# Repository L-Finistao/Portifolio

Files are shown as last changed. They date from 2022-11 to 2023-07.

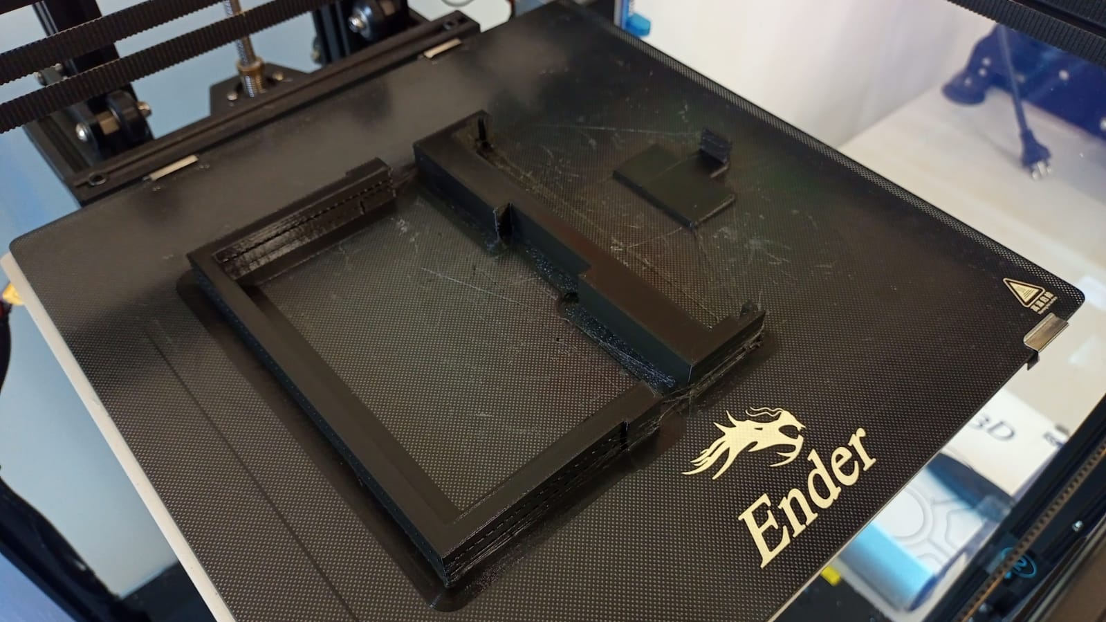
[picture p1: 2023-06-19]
Projeto/Fotos da montagem/Processo de impressão/impressão 08.jpg

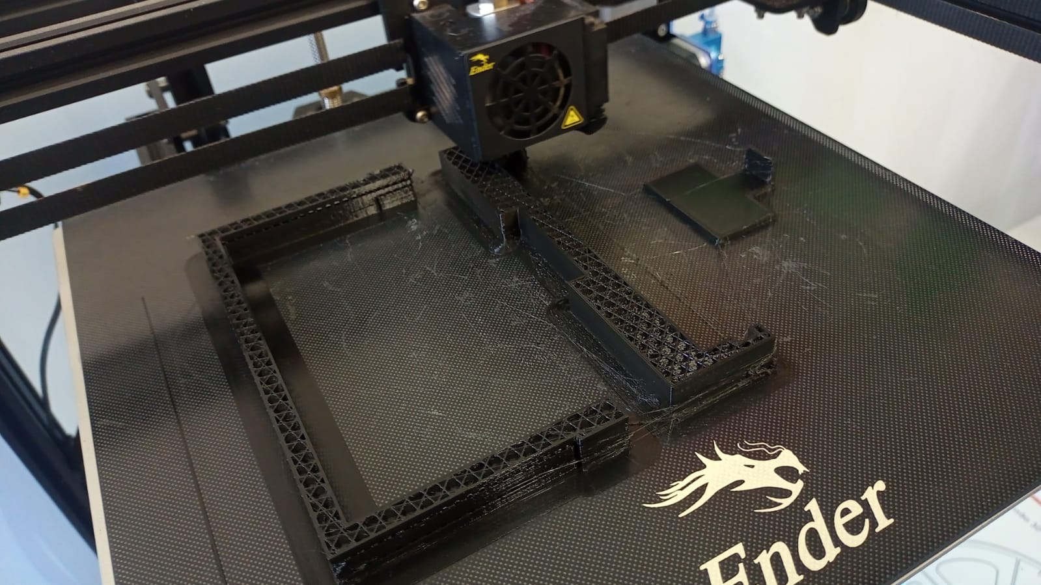
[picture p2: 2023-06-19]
Projeto/Fotos da montagem/Processo de impressão/impressão 01.jpg

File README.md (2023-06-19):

# Portifolio
Repositório de Portfólio para a matéria de Projeto Integrador I (PPRE8) IFSP Birigui-SP

Com o Link abaixo e possivel acessar o artigo que estamos Produzindo no Overleaf.

https://www.overleaf.com/read/fhdvfpwshqqs

## Projeto Robokeeper: Desenvolvimento de um Goleiro Robô

No projeto que desenvolvi, abordei a metodologia e os materiais utilizados para criar um goleiro robô chamado **Robokeeper** ou **Finisgol**. Meu objetivo era desenvolver um goleiro automatizado capaz de defender bolas em um jogo de futebol.

Na minha pesquisa, descrevi as etapas do projeto, começando pela análise e teste dos resultados, seguida pela otimização e melhorias. Organizei a metodologia em etapas para facilitar a compreensão e execução de cada atividade, o que contribuiu para o cumprimento dos meus objetivos e a validação dos resultados.

Além disso, apresentei um cronograma das atividades, detalhando as ações que seriam executadas até a Avaliação Final do Projeto. As etapas incluíram:

1. Levantamento dos componentes necessários.
2. Análise da viabilidade de utilizar visão computacional ou sensores ultrassônicos.
3. Prototipação do projeto por software.
4. Validação dos componentes.
5. Realização do orçamento.
6. Prototipação física.
7. Teste do protótipo.
8. Discussão e avaliação do projeto desenvolvido.
9. Entrega final do projeto.

Durante minha revisão bibliográfica, pesquisei informações sobre os motores de passo, destacando os diferentes tipos disponíveis no mercado e suas características. Optei pelo motor de passo "28byj-48", um motor de passo chinês com bom custo-benefício e especificações adequadas às necessidades do meu projeto.

Também abordei o sensor ultrassônico HC-SR04, explicando suas partes principais e seu funcionamento em três etapas. Esse sensor emite ondas ultrassônicas, recebe o eco do sinal emitido e calcula o tempo entre a emissão e a recepção do sinal para determinar a distância até um obstáculo.

Outro componente mencionado foi o LED (Light Emitting Diode), que é um dispositivo semicondutor capaz de transformar energia elétrica em luz. Expliquei os princípios de funcionamento dos LEDs e sua polarização.

No contexto do meu projeto, decidi entre utilizar visão computacional ou sensores ultrassônicos para captar o movimento da bola. Considerando meu conhecimento prévio, o tempo disponível, o custo e a complexidade da visão computacional, optei por utilizar sensores ultrassônicos para captar o movimento da bola.

Durante o desenvolvimento do projeto, adotei as seguintes etapas:

1. Estudo sobre o "Robokeeper" original.
2. Implementação de protótipos utilizando visão computacional e simuladores de circuitos Arduino.
3. Análise dos componentes mecânicos.
4. Montagem do protótipo físico.
5. Refinamento do software e componentes mecânicos.
6. Realização de testes para verificar o funcionamento do projeto.

Resumindo, descrevi a metodologia e os materiais utilizados no meu projeto de desenvolvimento de um goleiro robô, abordando desde a análise dos resultados até os testes finais. Apresentei informações sobre os

 motores de passo, sensores ultrassônicos, LEDs e minha escolha entre visão computacional e sensores ultrassônicos. Meu objetivo foi contribuir para a propagação da tecnologia robótica e o avanço das possibilidades na área de automação e inteligência artificial.

[Mapa Mental](/MapaMental.pdf)

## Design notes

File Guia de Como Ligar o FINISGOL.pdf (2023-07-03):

Manual Para Ligar e Operar FinisGOL
Problemas Não Resolvidos:

Botões:
Depois de soldado os fios foram analisados que o tipo de botão usado necessita de um resistor na extremidade do Fio.

Como Ligar?
Recomendo pedir ajuda ao Junior ou outro técnico para regular a Fonte de Tensão.

Pelos Botões Não estarem Funcionando Modifiquei o Código do Programa para Ligar sem a Necessidade do Botão. Código Disponível em Portfólio\Projeto\Código Alternativo Sem Botão no Github.
*Codigo já No Esp32

Verifique se os Fios Terras e Positivo estão ligados entre si e conectado a fonte geradora de Tensão.

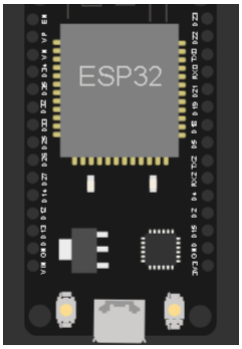
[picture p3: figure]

O Esp Utilizado tem essas Pinagens, o Terra que estamos unindo com o Motor é o mostrado abaixo

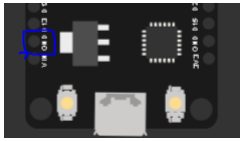
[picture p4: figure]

A Ligação do Motor Com a Ponte H é a seguinte.

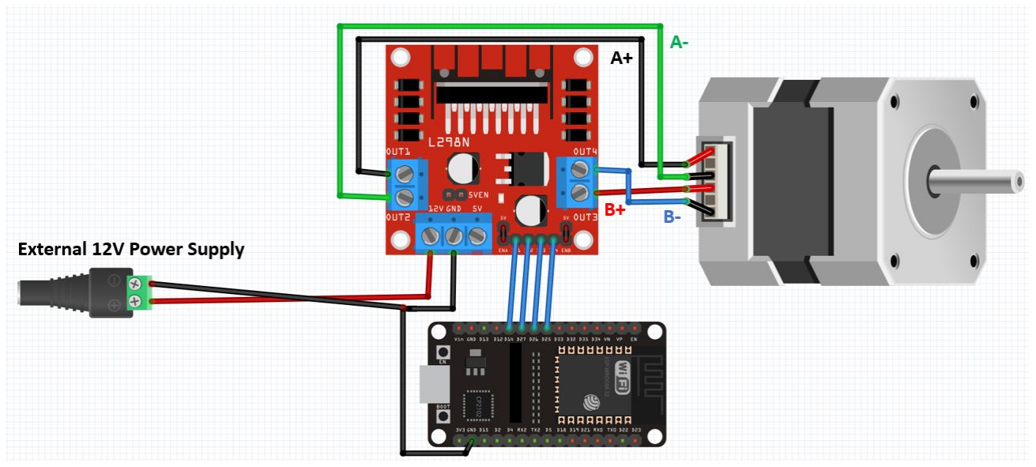
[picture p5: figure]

O Elemento na Imagem External 12V Power Supply utilizo a Fonte de Tensão que deixei proximo ao Projeto NO IF MAKER Certifique Se o Jumper que sai da Ponte H esteja ligado no Fio Vermelho do Gerador de Tensão e Corrente. e a junção entre o Terra da placa é ponte h no preto do Gerador.

Para que o Motor Opera na Faixa Ideal deve se regular A Fonte para Tensão: 12v e Corrente: 1.5A menos que isso o Motor/Goleiro apenas Vibra não Roda.

No Teste em Casa utilizei as Baterias mas pelo consumo do motor não foi viável manter pois após diminuir a tensão delas o motor não Roda, pois mesmo associando baterias para gerar a Tensão e Corrente Ideal em Pouco tempo ele fica em escala inferior ao Ideal.

O Esp 32 está conectado a um adaptador 12v que tem um botão para ligar a energia do Esp 32 o mesmo está conectado a Um Carregador. se não o ligar o esp 32 não Funcionará.

Identificação Visual de Funcionamento:

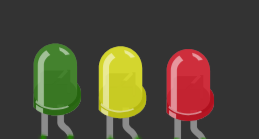
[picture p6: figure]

Ao Ligar o Esp 32 e Energizar Corretamente. o Led Verde Deve acender. ao Detectar um Objeto ele Aciona o Led Amarelo por 5 segundo ele deve voltar para o Verde

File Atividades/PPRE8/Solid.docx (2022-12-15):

O que é solid?

Solid (derivado de "dados vinculados a redes sociais") é um conjunto proposto de convenções e ferramentas para a construção de aplicativos sociais descentralizados com base nos princípios de dados vinculados. O Solid é modular e extensível e depende tanto quanto possível dos padrões e protocolos

Alguém já ouviu falar?

Só do termo SOLID que é um acrônimo para cinco postulados de design, destinados a facilitar a compreensão, o desenvolvimento e a manutenção de software.

Quem propôs?

Prof. Tim Berners-Lee, inventor da World Wide Web

Finalidade?

Verdadeira propriedade dos dados

Os usuários devem ter a liberdade de escolher onde seus dados residem e quem tem permissão para acessá-los. Ao desacoplar o conteúdo do próprio aplicativo, os usuários agora podem fazer isso.

Design modular

Como os aplicativos são desacoplados dos dados que produzem, os usuários poderão evitar o bloqueio do fornecedor, alternando perfeitamente entre aplicativos e servidores de armazenamento de dados pessoais, sem perder dados ou conexões sociais.

Reutilizando dados existentes

Os desenvolvedores poderão inovar facilmente criando novos aplicativos ou aprimorando os aplicativos atuais, enquanto reutilizam os dados existentes que foram criados por outros aplicativos.

Existe material em Português?

Não Encontramos

Como está a divulgação desse projeto? Como ficamos sabendo?

Não está sendo eficaz, através da professora.

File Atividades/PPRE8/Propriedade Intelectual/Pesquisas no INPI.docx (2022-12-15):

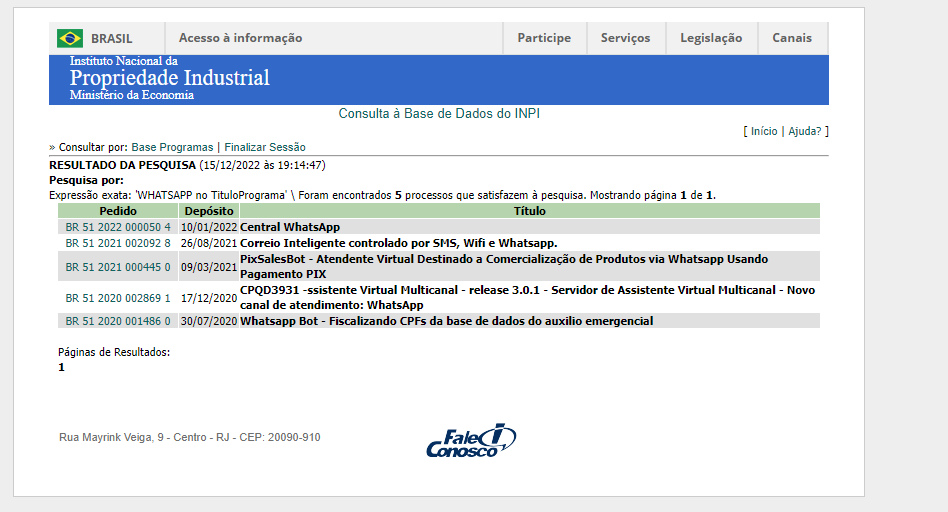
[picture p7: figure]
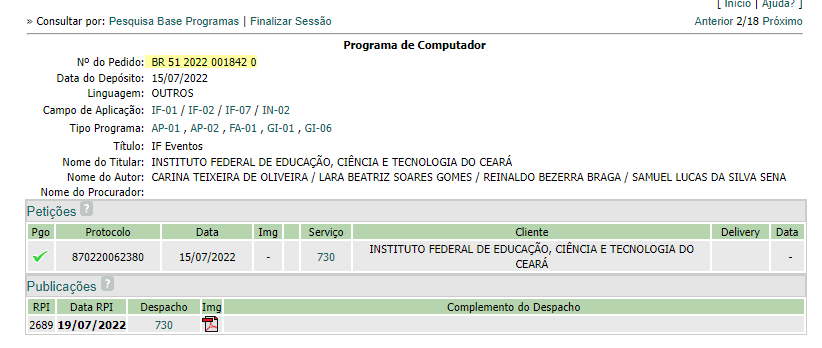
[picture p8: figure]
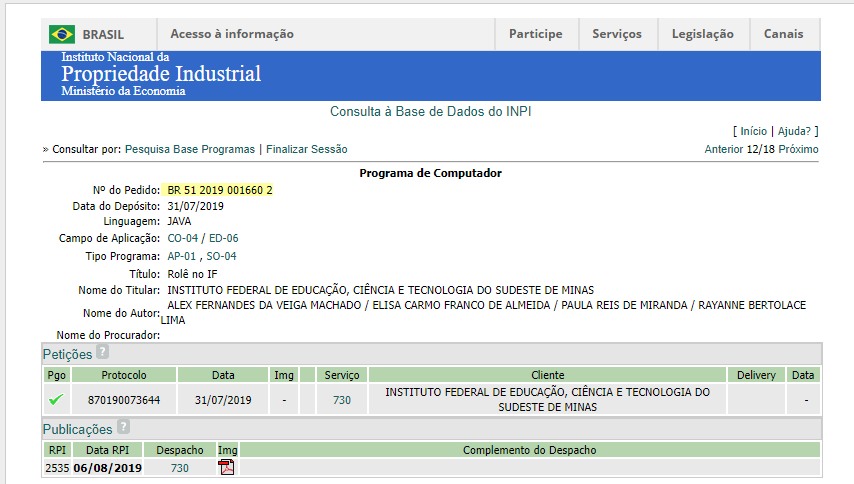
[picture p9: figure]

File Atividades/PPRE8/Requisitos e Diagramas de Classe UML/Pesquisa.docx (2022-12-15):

Pesquisas sobre:

- definição de requisitos do usuário, do sistema, funcionais e não funcionais
- BDD (o que é, finalidade, quando usar, exemplo)
- UML (o que é, para que usar, quais são os diagramas)
- Modelo de Domínio

BDD: (Behavior Driven Development)

O QUE É?:

Basicamente, o BDD utiliza um conceito de metodologia que prioriza o compartilhamento pela equipe de desenvolvimento, pelo time da qualidade e pelo pessoal da área de negócios. Como resultado, tem-se um produto que responde à expectativa do cliente, com a otimização do tempo de todos os envolvidos no processo.

FINALIDADE::

melhorar as funcionalidades, escrevendo códigos que vão ao encontro das necessidades dos clientes

UML

o que é:

A Linguagem de modelagem unificada (UML) foi criada para estabelecer uma linguagem de modelagem visual comum, semanticamente e sintaticamente rica, para arquitetura, design e implementação de sistemas de software complexos, tanto estruturalmente quanto para comportamentos

Por que usar?

Para escrever o projeto de forma padronizado de forma que outro ao ver possa entender o projeto.

Tipos de diagramas UML

A UML usa elementos e associa-os de diferentes maneiras para formar diagramas que representam aspectos estáticos ou estruturais de um sistema, além de formar diagramas comportamentais, que registram os aspectos dinâmicos de um sistema.

Diagramas UML estruturais

Diagrama de classes É o diagrama UML mais usado, e a principal base de qualquer solução orientada a objetos. Classes dentro de um sistema, atributos e operações, e a relação entre cada classe. Classes são agrupadas para criar diagramas de classes quando há uma diagramação de grandes sistemas.

Diagrama de componentes Exibe a relação estrutural de elementos do sistema de software, na maioria das vezes utilizado quando se trabalha com sistemas complexos com múltiplos componentes. Componentes se comunicam por meio de interfaces.

Diagrama de estrutura composta Diagramas de estrutura composta são utilizados para mostrar a estrutura interna de uma classe.

Diagrama de implementação Ilustra o hardware do sistema e seu software. É útil quando uma solução de software é implantada em diversas máquinas com configurações únicas.

Diagrama de objetos Mostra a relação entre objetos usando exemplos do mundo real e retrata um sistema em um determinado momento. Como os dados estão disponíveis dentro de objetos, eles podem ser utilizados para esclarecer as relações entre objetos.

Diagrama de pacotes Existem dois tipos especiais de dependências definidas entre pacotes: a importação do pacote e a mesclagem do pacote. Para revelar a arquitetura, os pacotes representam os diferentes níveis de um sistema. Dependências de pacotes podem ser marcadas para mostrar o mecanismo de comunicação entre os níveis.

Diagramas UML comportamentais

Diagramas de atividade Fluxos de trabalho de negócios ou operacionais representados graficamente para exibir a atividade de qualquer parte ou componente do sistema. Diagramas de atividade são usados como alternativa aos diagramas de máquina de estados.

Diagrama de comunicação Semelhante a diagramas de sequência, no entanto foca mensagens transmitidas entre objetos. A mesma informação pode ser representada usando um diagrama de sequência e outros objetos.

Diagrama da visão geral da interação Há sete tipos de diagramas de interação, e este diagrama exibe a sequência em que eles atuam.

Diagrama de sequência Mostra como objetos interagem entre si, e a ordem de ocorrência. Representam interações para um determinado cenário.

Diagrama de máquina de estados Semelhante a diagramas de atividade, eles descrevem o comportamento de objetos que se comportam de maneiras diferentes em seu estado atual.

Diagrama de tempo Assim como os diagramas de sequência, representa o comportamento de objetos em um determinado período de tempo. Se houver um único objeto, o diagrama é simples. Se houver mais de um objeto, as interações dos objetos são exibidas durante este período de tempo determinado.

Diagrama de caso de uso Representa uma determinada funcionalidade de um sistema, e foi criado para ilustrar a forma como as funcionalidades se relacionam e seus controladores internos e externos (atores).

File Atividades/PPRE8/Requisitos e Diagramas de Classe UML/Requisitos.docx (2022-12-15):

Requisito da Captação de dados

Dado: Que sou sistema de captação.

Quando: Receber um estímulo.

Então: Deve localizar o posicionamento da bola.

E: Enviar a posição ao robô.

Dado: Que sou sistema de captação.

Quando: Não detectar um estímulo.

Então: Continuar monitorando.

Requisito do usuário:

Dado: Que sou um usuário posicionado atrás da bola e o sistema está pronto para o chute.

Quando: Chutar a bola em direção ao gol.

Então: O estímulo é enviado ao sistema de captação de dados.

Dado: Que sou um usuário posicionado atrás da bola e o sistema não está pronto para o chute.

Quando: Chutar a bola em direção ao gol.

Então: O sistema não reagirá.

Requisito do Robô:

Dado: Que sou um robô.

Quando: Ao ser ligado

Então: Devo chegar a minha posição

Dado: Que sou um robô

Quando: Não estou na posição inicial

Então: Devo ligar um led vermelho e voltar à posição inicial

Dado: Que sou um robô

Quando: Estou na posição inicial

Então: Devo ligar um led verde e aguardar um estímulo.

Dado: Que sou um robô e não estou pronto.

Quando: Quando não recebo um estímulo.

Então: Devo retornar a posição inicial.

Dado: Sou o robô e estou pronto.

Quando: Quando receber um estímulo.

Então: Reagir ao estímulo defendendo a bola.

Dado: Sou o robô e não estou pronto.

Quando: Quando receber um estímulo.

Então: Não reage ao estímulo e não defende a bola.

Dado: Sou o robô e estou pronto.

Quando: Quando não receber um estímulo.

Então: Não deve fazer nada.

E: Aguardar um estímulo.

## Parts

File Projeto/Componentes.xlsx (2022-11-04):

Componentes | Modelo | Un. | Dispon. | Valor Nasc. | Valor Intern. | Link Internacional | Link Nacional
Esp32 | esp8266 | 1 | 1 | R$36 | R$9.89 | https://pt.aliexpress.com/item/1005001666897038.html?_t=pvid%3A22f0c26b-53df-4900-afe5-67cccc9e0f71 | https://produto.mercadolivre.com.br/MLB-1759659294-esp32-esp-32-esp-wroom-32-pronto-entrega-_JM
sensor ultrassônico | hc-sr04 | 1 | 1 | R$15 | R$4.51 | https://pt.aliexpress.com/item/32901149409.html?pdp_ext_f=%7B%22sku_id%22%3A%2265822750914%22%7D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 | https://produto.mercadolivre.com.br/MLB-1460401421-modulo-sensor-ultra-snico-distncia-hc-sr04-para-arduino-_JM
Motor de Passo | 28byj-48 | 1 | 0 | R$18.90 | R$2.58 | https://pt.aliexpress.com/item/32889788942.html?_t=pvid%3A7a75940b-ec81-4486-8ceb-3fe572d313fe | https://produto.mercadolivre.com.br/MLB-808282374-motor-de-passo-28byj-48-5v-com-driver-uln2003-_JM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
Total |  |  |  | R$69.90 | R$16.98 | Valores Internacional Sem o Frete

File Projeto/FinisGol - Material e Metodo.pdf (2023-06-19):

23

# 3 MATERIAIS E MÉTODOS

### 3.0.1 Materiais

Nesta seção serão descritos os materiais e métodos que serão utilizados para a execução deste projeto

Parte do projeto consiste num estudo sobre a tecnologia desenvolvida pela 4atenção GmbH Co. KG. Que consistem em um dispositivo esportivo. Utilizado em eventos esportivos pelo mundo como um módulo de ativação que chama a atenção para evento e parque de entretenimento. Para tanto, serão utilizados o software Virtual breadboard avatar hardware e SimulIDE para ambiente Windows e o editor de código visual Studio para codificar códigos necessários para a prototipação. Para as pesquisas e desenvolvimento de programas serão utilizados notebooks e máquinas pessoas dos alunos envolvidos.

### 3.0.2 Métodos

Para o desenvolvimento do projeto etapas foram estabelecidas, sendo elas:

1ª Etapa: Revisão bibliográfica. Nesta etapa se dará a localização e leitura de diversas fontes de informações sobre o desenvolvimento e funcionamento do goleiro robô denominado “Robokeeper”. Investigar os tipos de sensores, plataformas e recursos que se aplicam e permitam o desenvolvimento do projeto. Serão contempladas aplicações nos domínios científico e mercadológico. O objetivo é permitir que a equipe compreenda como esta tecnologia se porta e tem sido utilizada

2ª Etapa: Desenvolver protótipo através de simuladores, utilizando os componentes selecionados na primeira etapa nesta etapa será projetado e implementado um protótipo em software, implementado na plataforma do Arduino.

3ª Etapa: Estudar os componentes mecânicos utilizados para a confecção estrutural do dispositivo; construir o protótipo físico a ser utilizado para a integração dos componentes descritos na primeira etapa e testados via software na segunda etapa.

4ª Etapa: Incluir os componentes e sensores já investigados na primeira etapa; estudar a linguagem adequada para programar na plataforma escolhida.

5ª Etapa: Definir a trajetória a ser monitorada pelo robô; criar programa para a plataforma desejada inseridos na parte mecânica; estudar a linguagem e técnica que permitirá que o monitoramento seja eficaz.

Capítulo 3. | Materiais e métodos | 24

6ª Etapa: Análise e teste dos resultados; Otimização e melhorias. Organizar a metodologia do projeto em etapas contribui para a compreensão e execução de cada atividade, facilitando assim o cumprimento e validação de cada objetivo considerando a importância do conhecimento produzido a partir deste projeto, pretende-se divulgá-lo para a comunidade interna e externa ao campus. Desta forma, objetiva-se na contribuir para propagação desta tecnologia.

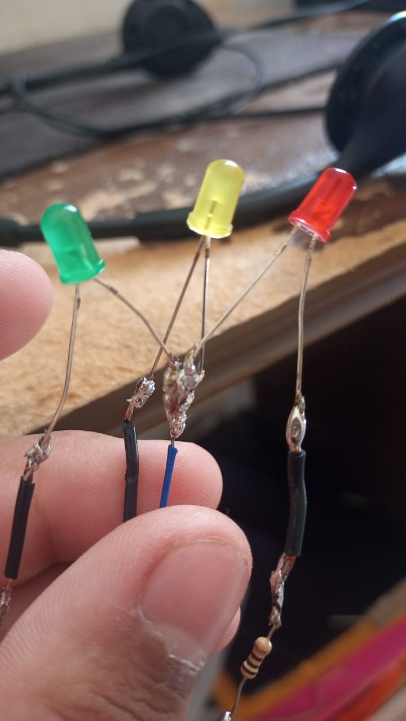
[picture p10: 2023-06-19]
Projeto/Fotos da montagem/Montagem do circuito/Solda de componentes.jpg

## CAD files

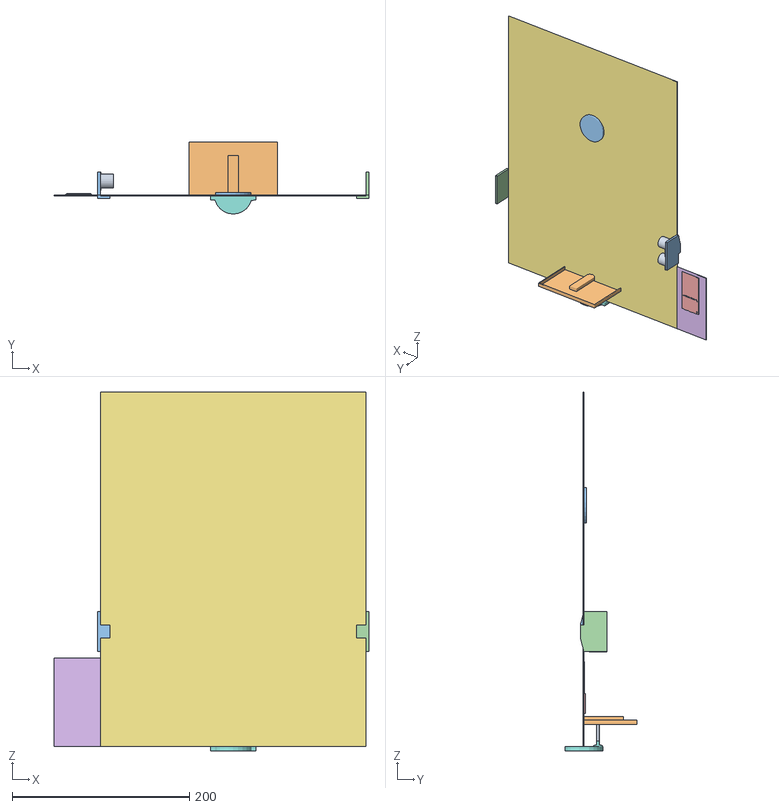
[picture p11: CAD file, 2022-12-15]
Projeto/Projeto_Modelo_Simples_3d.obj
355.0 x 81.3 x 405.0
Mesh1 Sensor1 Model
Mesh2 Gol1 Model
Mesh3 Suporte1_1 Model
Mesh4 Suporte1_2 Model
Mesh5 Esp32_1 Model
Mesh6 Base_Sistema1 Model
Mesh7 Base1 Model
Mesh8 Motor1 Model
Mesh9 Eixo_Apoio1 Model
Mesh10 Goleiro1 Model
Mesh11 Model

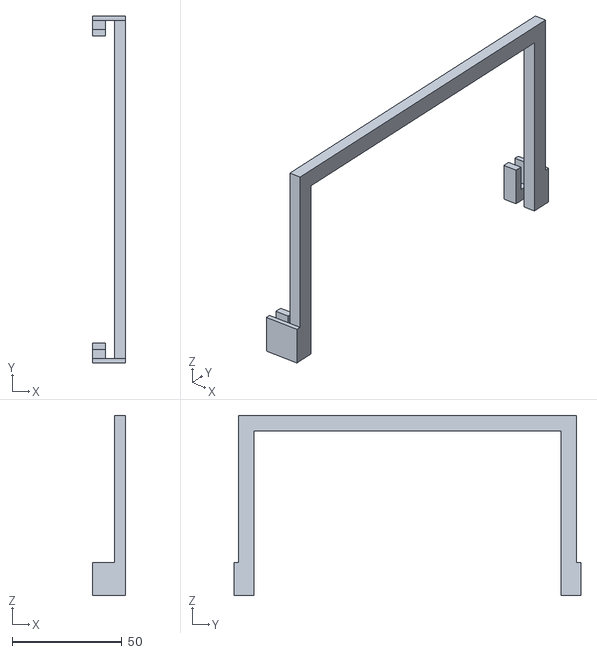
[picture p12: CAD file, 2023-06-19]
Projeto/arquivos das Impressões/Gol_P2.stl
15.0 x 158.0 x 82.0

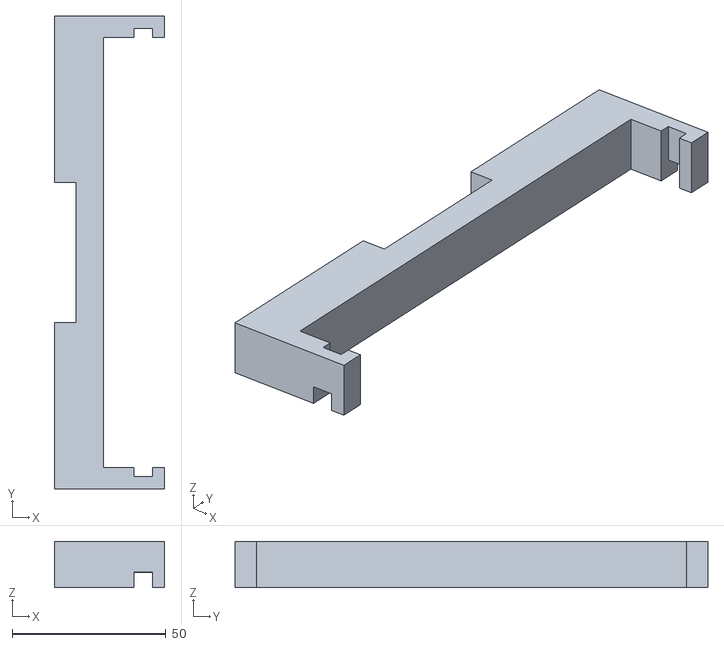
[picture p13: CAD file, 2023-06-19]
Projeto/arquivos das Impressões/GolP1.stl
36.0 x 154.0 x 15.0

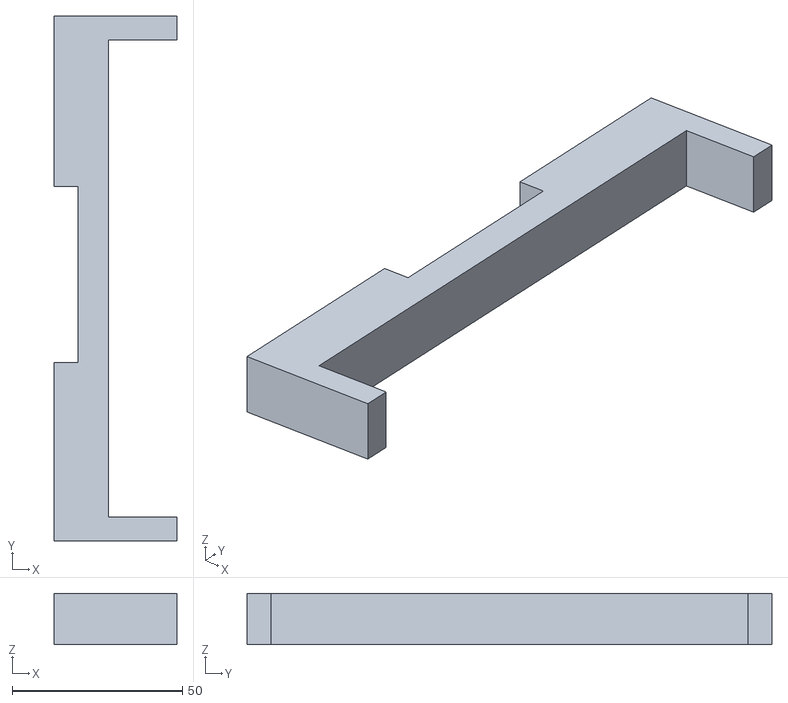
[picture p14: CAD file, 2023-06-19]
Projeto/arquivos das Impressões/Suporte Gol.stl
36.0 x 154.0 x 15.0

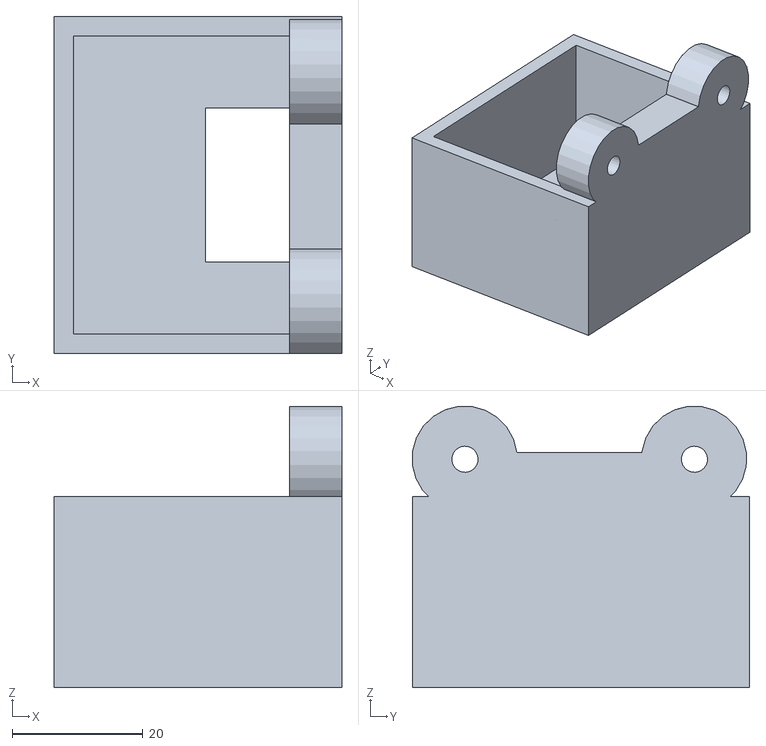
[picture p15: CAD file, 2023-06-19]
Projeto/arquivos das Impressões/Sem nome.stl
44.0 x 51.6 x 43.0

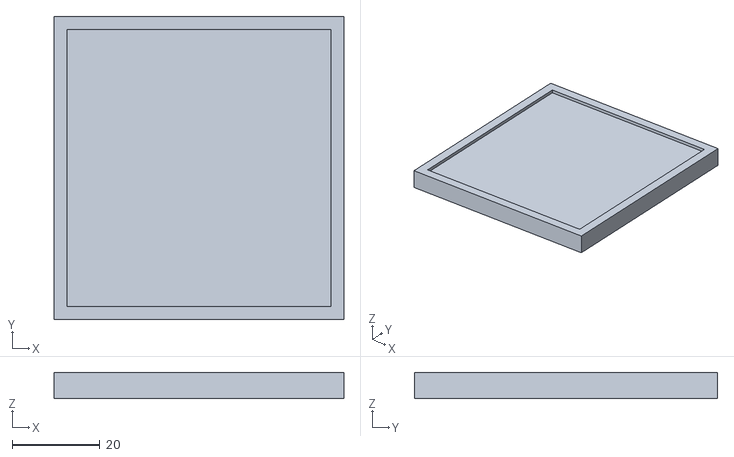
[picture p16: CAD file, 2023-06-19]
Projeto/arquivos das Impressões/Tampa Button.stl
66.0 x 69.0 x 6.00

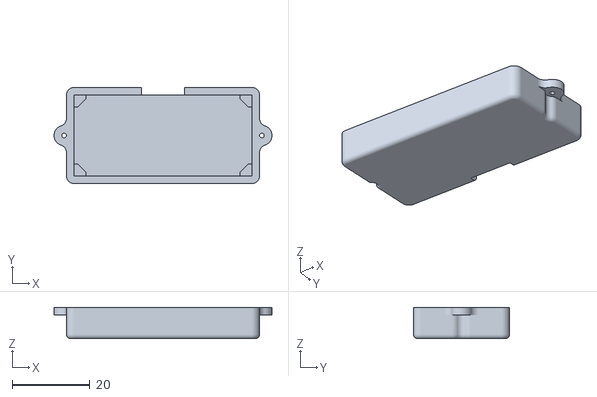
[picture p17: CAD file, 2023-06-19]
Projeto/arquivos das Impressões/bottom_v2.stl
56.2 x 24.8 x 8.00

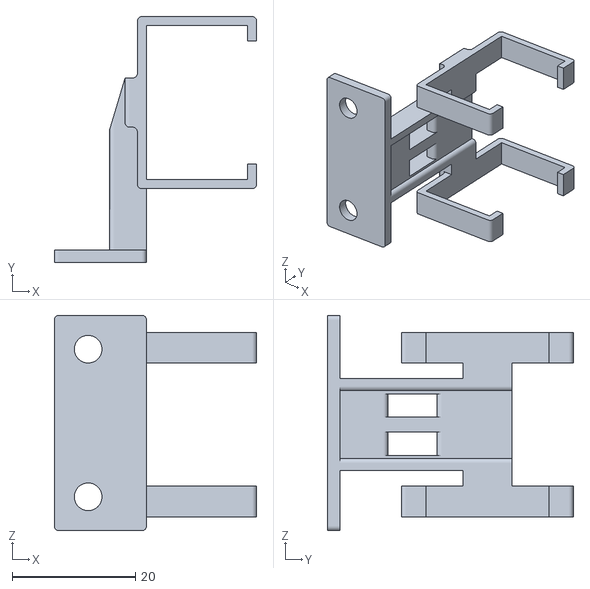
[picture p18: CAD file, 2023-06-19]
Projeto/arquivos das Impressões/12_Halter_Ultraschall_Entferungsmesser_V1.4_Final.STL
32.9 x 40.0 x 35.0

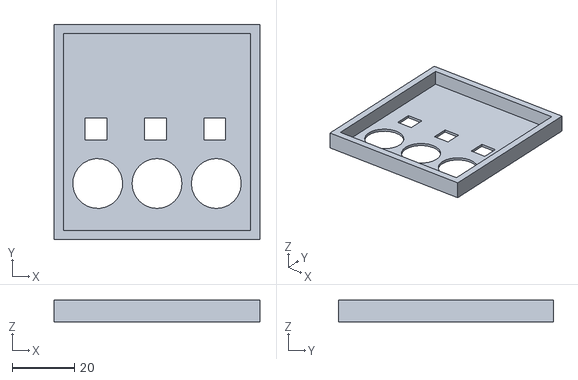
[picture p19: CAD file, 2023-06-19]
Projeto/arquivos das Impressões/Top.stl
66.0 x 69.0 x 7.00

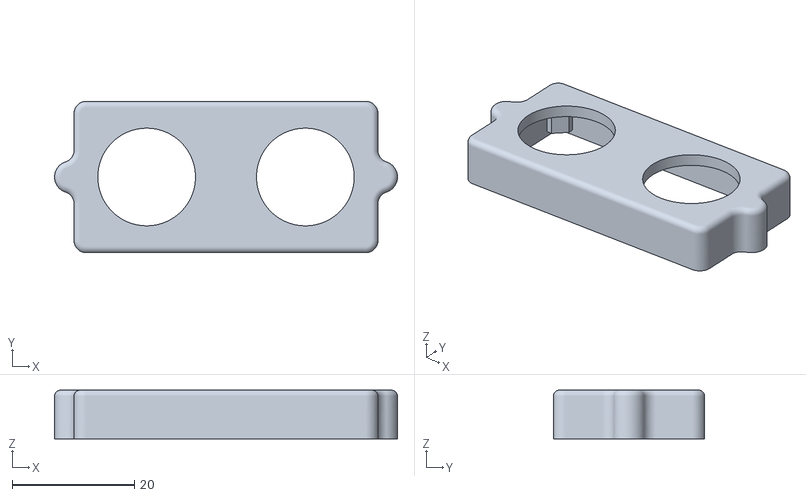
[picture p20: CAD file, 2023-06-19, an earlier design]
Projeto/arquivos das Impressões/top (1).stl
56.2 x 24.8 x 8.00

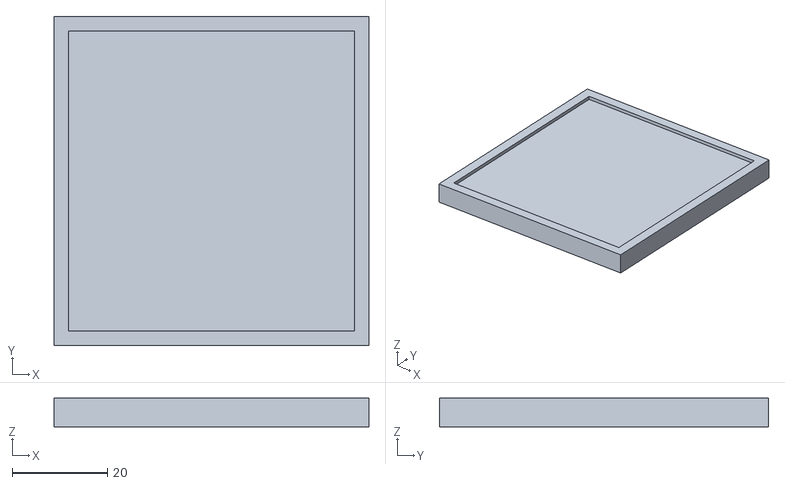
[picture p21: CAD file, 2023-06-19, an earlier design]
Projeto/arquivos das Impressões/Tampa Button (2).stl
66.0 x 69.0 x 6.00

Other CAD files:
Projeto/Modelo 3d & Imagens/Modelo Fisico.skp
Projeto/Projeto_Modelo_Simples_3d.skp

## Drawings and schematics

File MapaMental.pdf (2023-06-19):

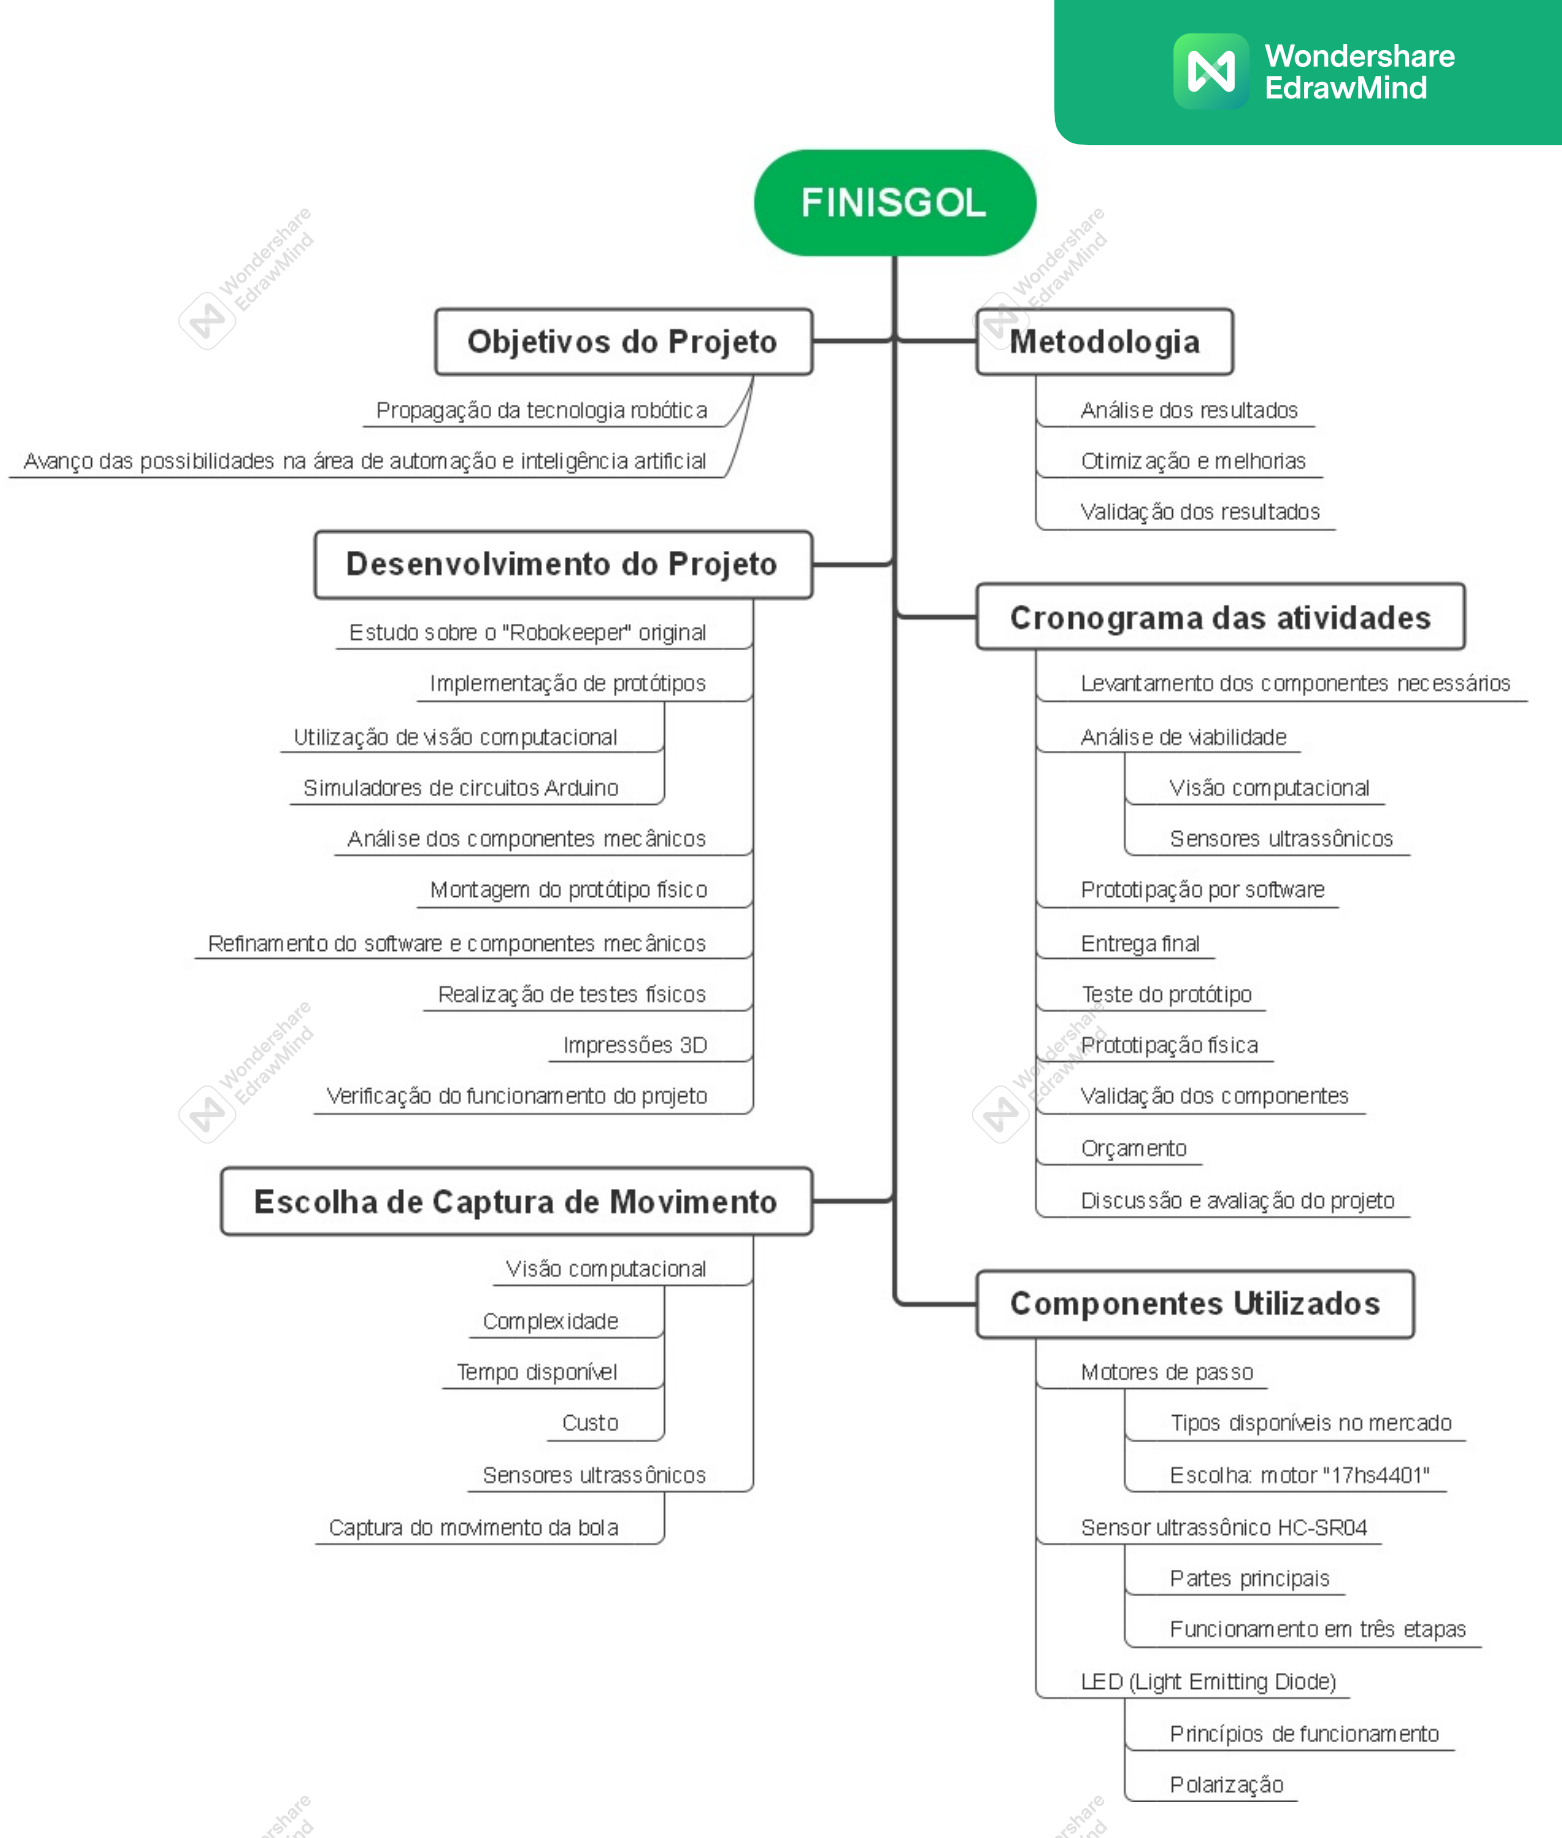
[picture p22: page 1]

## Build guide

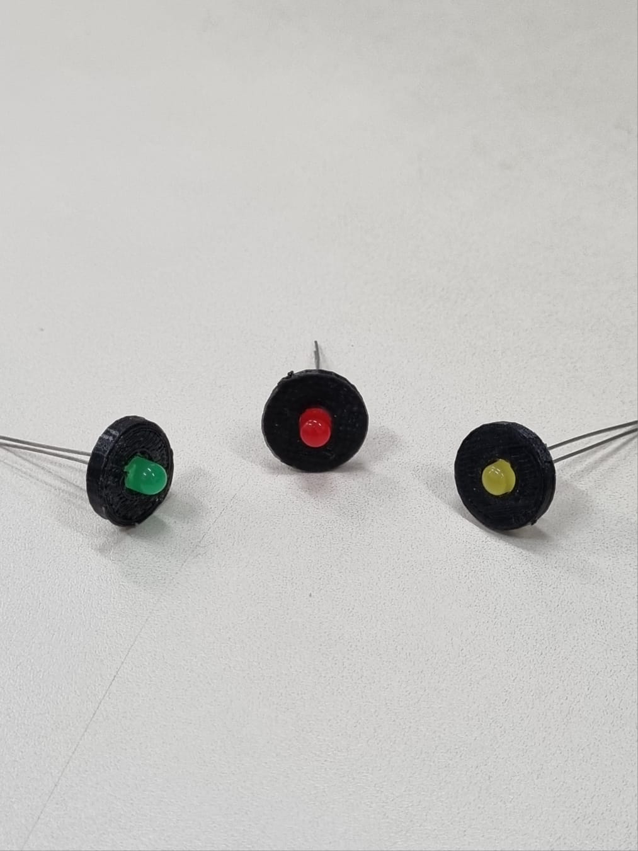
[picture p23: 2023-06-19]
Projeto/Fotos da montagem/impressão feitas/impressão 05.jpg

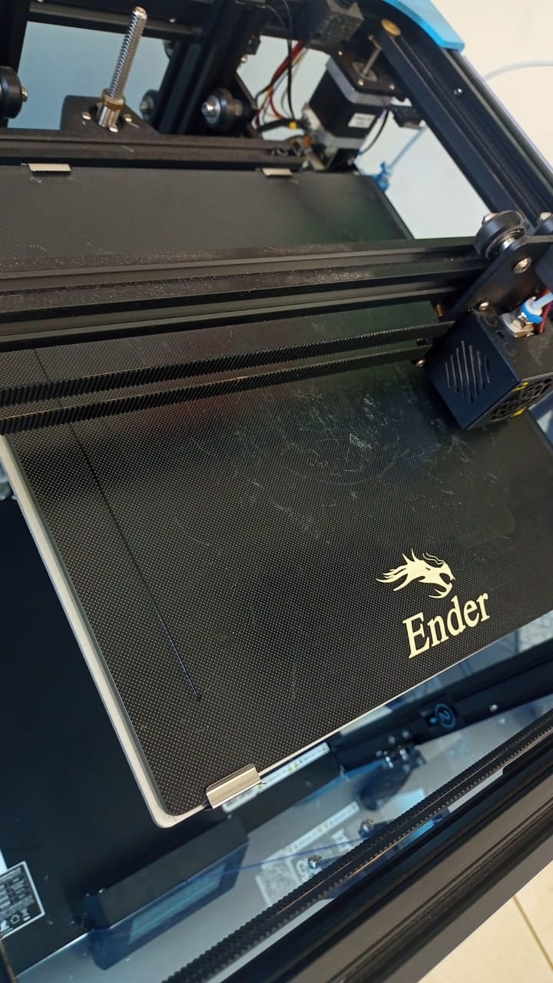
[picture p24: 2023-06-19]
Projeto/Fotos da montagem/Processo de impressão/impressão 02.jpg

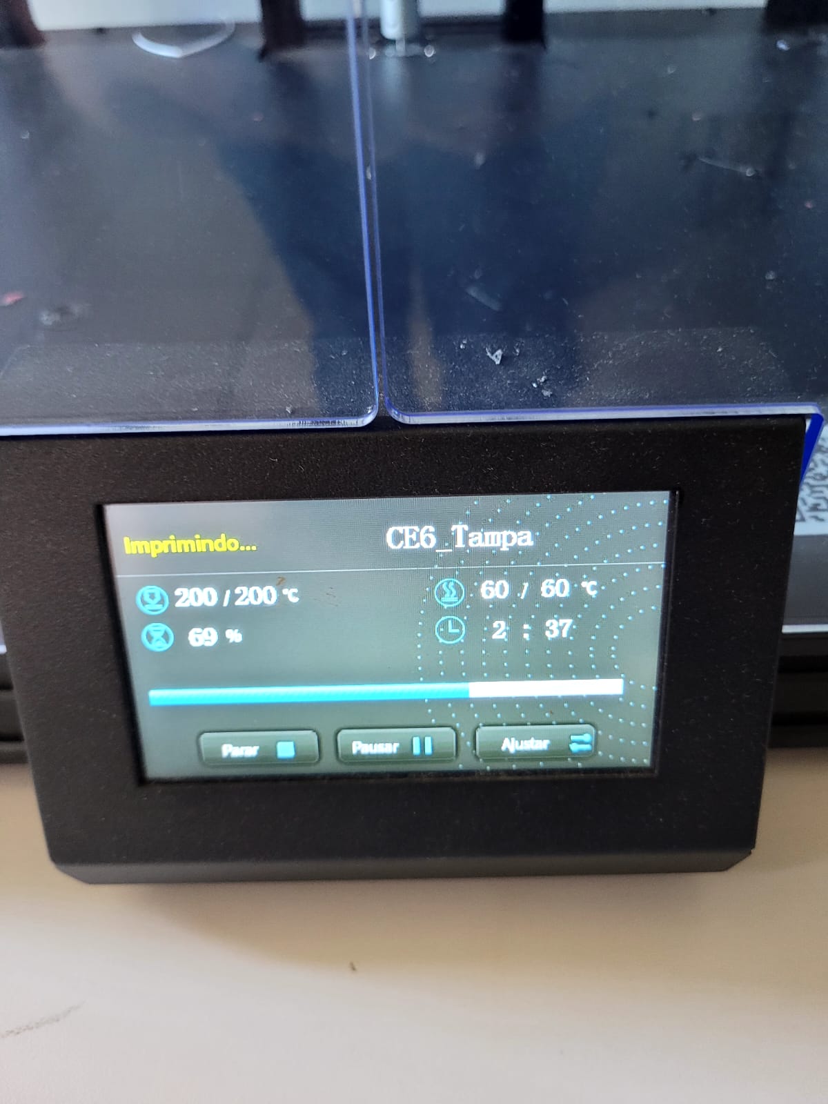
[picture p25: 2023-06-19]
Projeto/Fotos da montagem/Processo de impressão/impressão 10.jpg

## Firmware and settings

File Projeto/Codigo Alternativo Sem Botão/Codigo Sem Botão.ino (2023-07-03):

#define BLYNK_TEMPLATE_ID "TMPL2PbaYo_Qu"
#define BLYNK_TEMPLATE_NAME "FinisGOL"
#define BLYNK_AUTH_TOKEN "bWVVgzfUVxggAGKzswGmHjF0ynVwYLwM"


#include <Arduino.h>
#include <freertos/FreeRTOS.h>
#include <freertos/task.h>
#include <stdio.h>
#include <Stepper.h>
#include <WiFi.h>
#include <WiFiClient.h>
#include <BlynkSimpleEsp32.h>

#define IN1 14
#define IN2 27
#define IN3 26
#define IN4 25


//Pinos do Led
#define LED_VERDE_PIN 13
#define LED_AMARELO_PIN 12
#define LED_VERMELHO_PIN 33


//Pinos do Sensor 
#define trigger_pin 5
#define Echo_pin 18


#define BOTAO_DESLIGAR_PIN 15
#define BOTAO_LIGAR_PIN_1 2


long duration;
int distance;

// Task handles
TaskHandle_t sensorTaskHandle;
TaskHandle_t motor1TaskHandle;
TaskHandle_t motor2TaskHandle;


char auth[] = BLYNK_AUTH_TOKEN;
char ssid[] = "LucasF";
char pass[] = "";

bool systemon = true;

// Define o range máximo e mínimo do sensor ultrassônico
int RANGE_MAXIMO = 408;
const int steps_per_rev = 200;  // Set to 200 for NIMA 17

BlynkTimer timer;
int value0, value1, value2, value3;

Stepper motor(200, 14, 27, 26, 25);


BLYNK_WRITE(V1)
{
  value0 = param.asInt();
  RANGE_MAXIMO = value0;
  Blynk.virtualWrite(V0,RANGE_MAXIMO);
}


void setup() {
  pinMode(trigger_pin, OUTPUT);  // configure the trigger_pin(D9) as an Output
  pinMode(Echo_pin, INPUT);
  pinMode(LED_VERDE_PIN, OUTPUT);
  pinMode(LED_AMARELO_PIN, OUTPUT);
  pinMode(LED_VERMELHO_PIN, OUTPUT);

  motor.setSpeed(50);
  Serial.begin(115200);
  //Blynk.begin(auth, ssid, pass);   


  // Create tasks
 // xTaskCreatePinnedToCore(controllerTask, "ControllerTask", 2048, NULL, 2, NULL, 1);
  xTaskCreatePinnedToCore(sensorTask, "SensorTask", 2048, NULL, 1, &sensorTaskHandle, 0);
  
  digitalWrite(LED_VERDE_PIN, HIGH);
  digitalWrite(LED_AMARELO_PIN, LOW);
  digitalWrite(LED_VERMELHO_PIN, LOW);

  systemon = true;
}

void loop() {

}
void sensorTask(void *pvParameters) {
      int teste = 200;

  while (1) {
    
    digitalWrite(trigger_pin, LOW);  // set trigger signal low for 2us
    delayMicroseconds(2);

    /*send 10 microsecond pulse to trigger pin of HC-SR04 */
    digitalWrite(trigger_pin, HIGH);  // make trigger pin active high
    delayMicroseconds(10);            // wait for 10 microseconds
    digitalWrite(trigger_pin, LOW);   // make trigger pin active low

    /*Measure the Echo output signal duration or pulse width */
    duration = pulseIn(Echo_pin, HIGH);  // save time duration value in "duration" variable
    distance = duration * 0.034 / 2;     // Convert pulse duration into distance
    
    Serial.print("Distance: ");
    Serial.print(distance);
    Serial.println(" cm");

    if (distance <= 11) {
     Serial.print("Entre 5 e 13 ");
      digitalWrite(LED_VERDE_PIN, LOW);
      digitalWrite(LED_AMARELO_PIN, HIGH);
      digitalWrite(LED_VERMELHO_PIN, LOW);
      motor.step(-50);

       delay(1000);
      digitalWrite(LED_VERDE_PIN, HIGH);
      digitalWrite(LED_AMARELO_PIN, LOW);
      digitalWrite(LED_VERMELHO_PIN, LOW);


    }
    else if (distance <= 20){
      digitalWrite(LED_VERDE_PIN, LOW);
      digitalWrite(LED_AMARELO_PIN, HIGH);
      digitalWrite(LED_VERMELHO_PIN, LOW);
      motor.step(50);

       Serial.print("Entre 13 e 30 ");
       delay(1000);
      digitalWrite(LED_VERDE_PIN, HIGH);
      digitalWrite(LED_AMARELO_PIN, LOW);
      digitalWrite(LED_VERMELHO_PIN, LOW);

    }  
    delay(80);


}  
}

void controllerTask(void *pvParameters) {
  while (1) {
    // Ler o estado dos botões
    int desligar = digitalRead(BOTAO_DESLIGAR_PIN);
    int ligar = digitalRead(BOTAO_LIGAR_PIN_1);
    
    // Desligar o sistema se o botão de desligar for pressionado
    if (desligar == HIGH) {
           Serial.print("bUTÃO 1");

    }
    
    // Ligar os pinos 35 e 34 se o botão de ligar for pressionado
    if (ligar == HIGH) {
      
           Serial.print("bUTÃO 2");
    }
    
    // Pequeno atraso para evitar leituras falsas
    delay(100);
  }
}

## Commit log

2022-09-29 Cronograma Estabelecido para a execusão do projeto
2022-09-29 Cronograma definido para o projeto
    Neste arquivo consta o cronograma definido para o projeto
2022-09-29 Arquivo contendo a Metodologia que usaremos
    Neste arquivo temos a metodologia que usaremos para realizar o projeto
2022-12-01 Atualização de Modelo e componentes
    [Modelo Fisico.skp]
2022-12-15 Reorganização das Pastas
    [Componentes.xlsx, Modelo Fisico.skp, Projeto_Modelo_Simples_3d.obj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]
2023-06-19 Update Portifolio
    [12_Halter_Ultraschall_Entferungsmesser_V1.4_Final.STL, GolP1.stl, Gol_P2.stl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]

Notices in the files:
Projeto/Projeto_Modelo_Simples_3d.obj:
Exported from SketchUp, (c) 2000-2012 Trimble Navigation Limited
